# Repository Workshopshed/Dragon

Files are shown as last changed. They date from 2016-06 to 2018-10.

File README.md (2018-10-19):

# Dragon Detector
## Dragonboard 410c Project
This is the source code for the Dragon Detector project for more details of the electronics and build see https://www.element14.com/community/people/Workshopshed/blog and for the mechanical aspects see http://workshopshed.com/category/myprojects/dragon-detector/

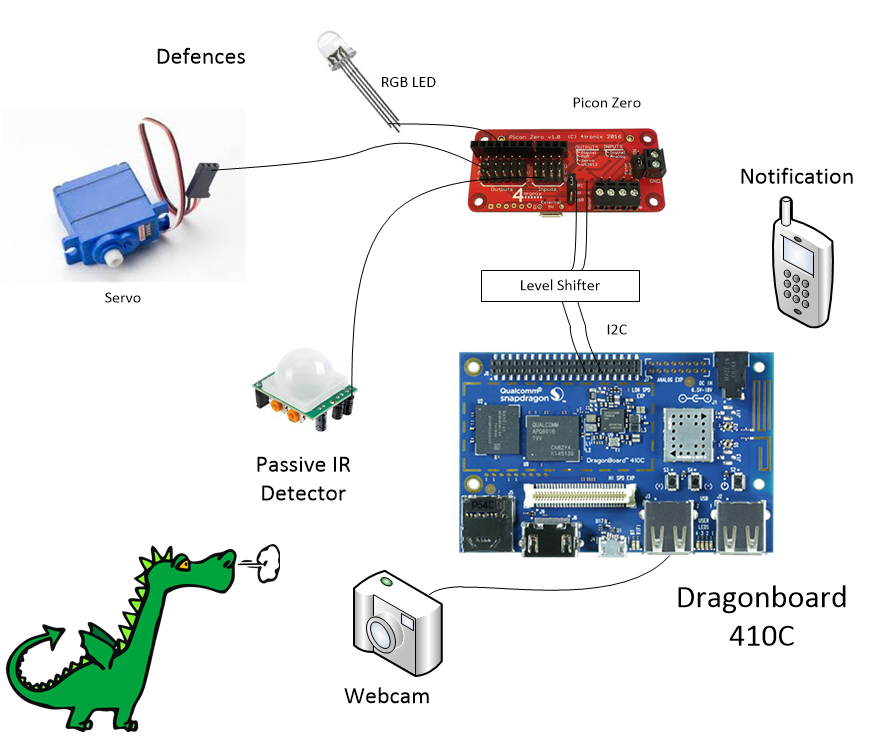
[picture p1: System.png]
System Diagram


Here it is in action, click image to see video

Demo Video (https://www.youtube.com/watch?v=9NGkGyWplvQ)

A short talk on the project https://skillsmatter.com/skillscasts/8225-linuxing-in-london

## Software Dependencies

Dropbox API - https://www.dropbox.com/developers/documentation/python#install

piconzero - http://4tronix.co.uk/blog/?p=1224

IFTTT Maker API - https://ifttt.com/maker

OpenCV - http://opencv.org/

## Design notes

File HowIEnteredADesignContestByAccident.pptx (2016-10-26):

## How I entered a $5000 design challenge by accident

By Andy Clark

## What is a design challenge?

- Free Stuff
- Company promotion
- Proposal
- Build
- Write up / Video
- Prizes

## 2015 Enchanted Objects Design Challenge

- Add enchantment to an every day object
- 16 weeks of soldering, 3D printing, coding and writing
- Won the grand prize Trip to New York Makers Faire

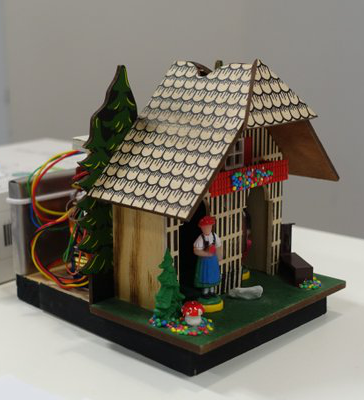
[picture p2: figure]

No More Design Challenges!

## March 2016

Tell us what you would make with a DragonBoard 410c for a chance to win your own

Qualcomm

I am entering this contest and wish your vote when polls open

Clem Martins

Some ideas are so far west they are another planet

Mark B

I'm really tempted to put in a completely ridiculous entry

Nico teWinkel

## My Entry

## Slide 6

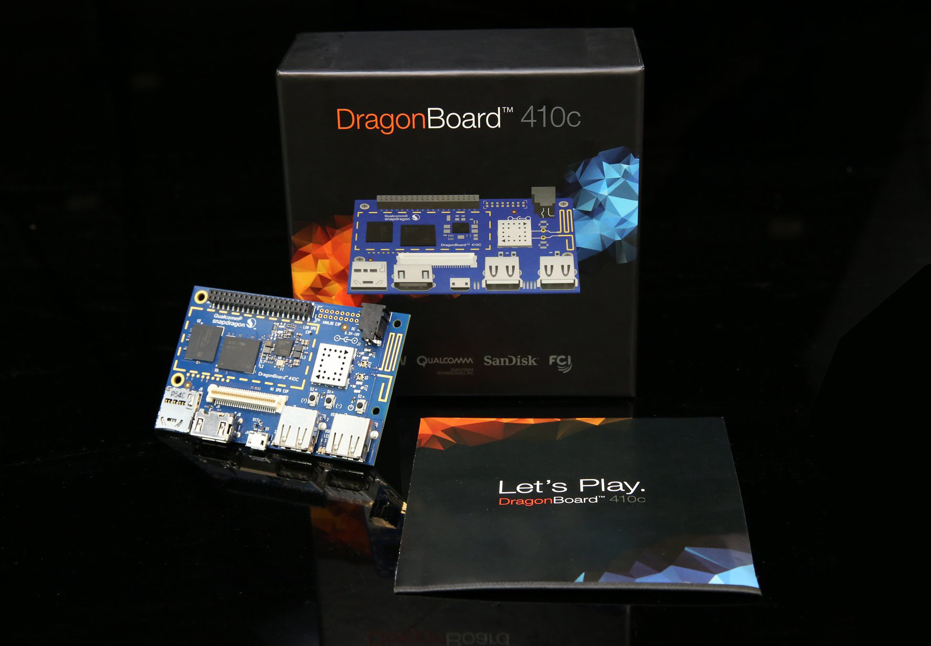
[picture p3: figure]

Photo thanks to Arrow.Com

## Setting up the DragonBoard

- Preinstalled Android image
- Community support at 96boards.org
- Reflashed with Debian image provided by Linaro

## OpenCV

“(Open Source Computer Vision) is a library of programming functions mainly aimed at real-time computer vision.”

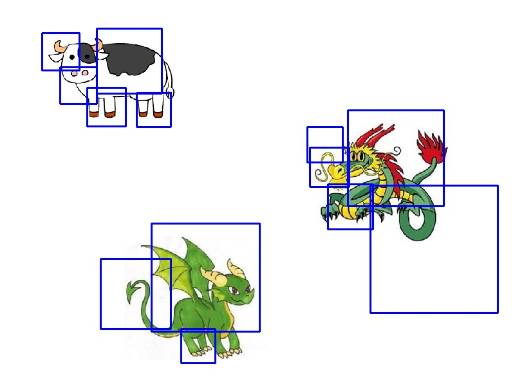
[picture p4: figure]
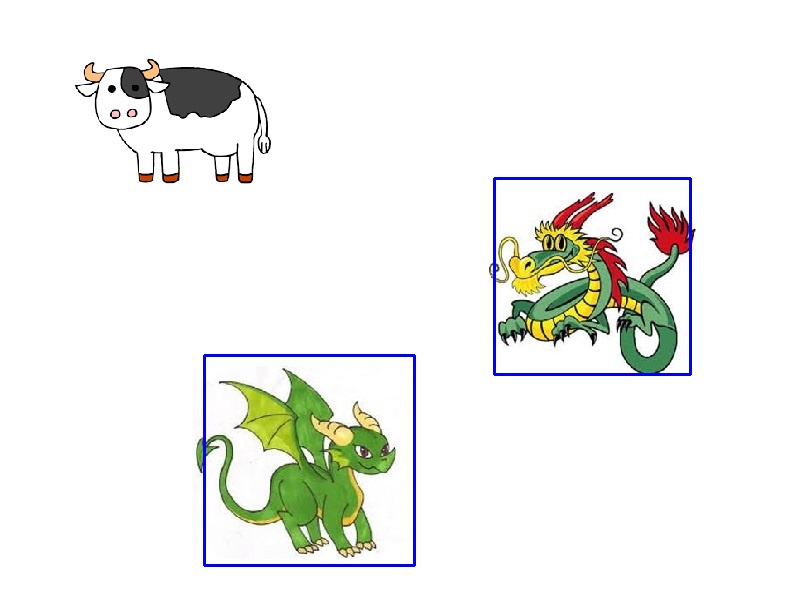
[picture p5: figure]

## GPIO General Purpose Input / Output

- Install drivers such as LibSoc
- No PWM
- 1.8v
- Ref: https://github.com/jackmitch/libsoc/blob/master/static-docs/docs/index.md

## Electronics

- Level Shifters
- Passive IR module
- USB Camera
- LEDs

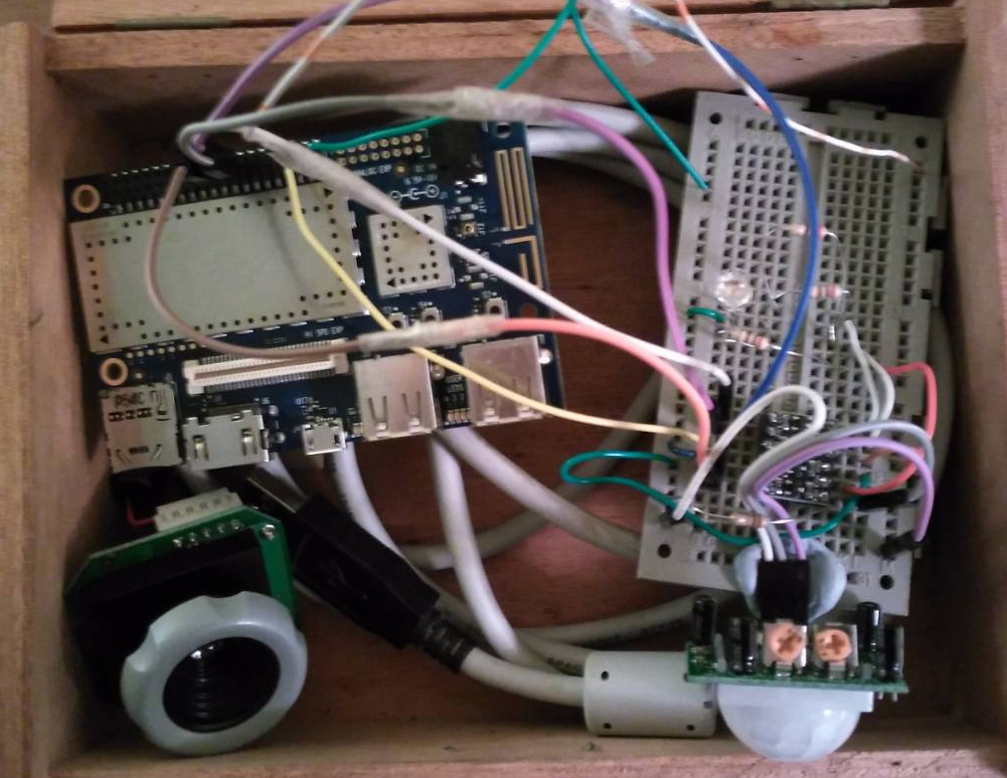
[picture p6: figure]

## So did I win $5000?

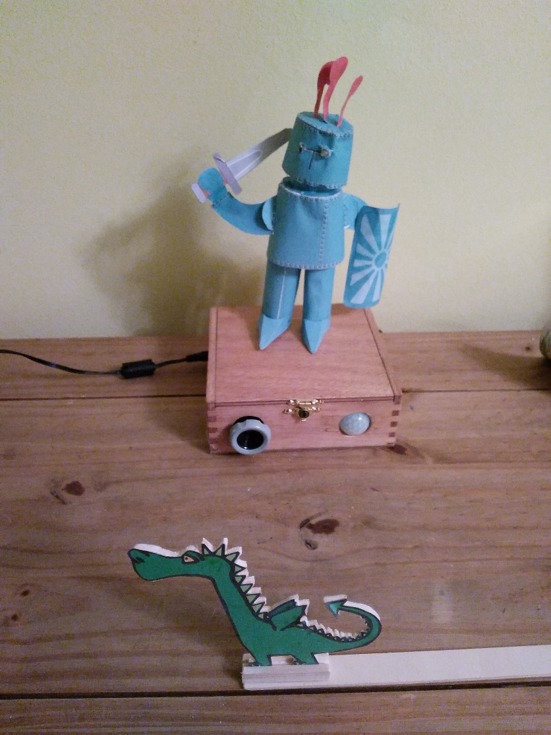
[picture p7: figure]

- Qualcomm Developer of the Month
- Arrow.com sponsoring

## Dragon Detector V2

- 3D Printed model
- PiConZero module for PWM
- Demo

## Questions?

https://wsshd.com/DragonDectector

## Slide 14

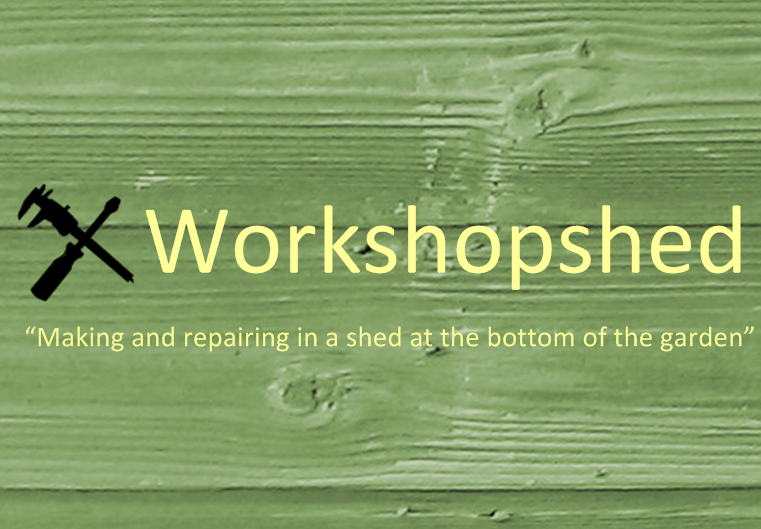
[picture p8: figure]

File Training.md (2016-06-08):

# Details of the training process for the Cascade Classifier in OpenCV

[Details of the OpenCV code development](https://www.element14.com/community/people/Workshopshed/blog/2016/05/20/dragonboard-410c-opencv)

The training application is very hungry for memory and used about 2.5GB on my system. It ran one of my CPUs at between 50% and 100%.

Conveniently the training application tells you how long it runs for, so on my first pass it tool 13 minutes for stage one and finished in about half an hour

Here's the output from the second run where I had a lot more images and set the false alarm rate much lower.

```
opencv_traincascade.exe -data Cascade -vec Dragons.vec -bg Negative.info -numPos 90 -numNeg 2078 -maxFalseAlarmRate 0.05 -numStages 5 -w 50 -h 50 -mode ALL
PARAMETERS:
cascadeDirName: Cascade
vecFileName: Dragons.vec
bgFileName: Negative.info
numPos: 90
numNeg: 2078
numStages: 5
precalcValBufSize[Mb] : 1024
precalcIdxBufSize[Mb] : 1024
acceptanceRatioBreakValue : -1
stageType: BOOST
featureType: HAAR
sampleWidth: 50
sampleHeight: 50
boostType: GAB
minHitRate: 0.995
maxFalseAlarmRate: 0.05
weightTrimRate: 0.95
maxDepth: 1
maxWeakCount: 100
mode: ALL

===== TRAINING 0-stage =====
<BEGIN
POS count : consumed   90 : 90
NEG count : acceptanceRatio    2078 : 1
Precalculation time: 11.939
+----+---------+---------+
|  N |    HR   |    FA   |
+----+---------+---------+
|   1|        1|        1|
+----+---------+---------+
|   2|        1|        1|
+----+---------+---------+
|   3|        1| 0.298845|
+----+---------+---------+
|   4|        1| 0.326275|
+----+---------+---------+
|   5|        1| 0.100096|
+----+---------+---------+
|   6|        1|0.0375361|
+----+---------+---------+
END>
Training until now has taken 0 days 1 hours 53 minutes 16 seconds.

===== TRAINING 1-stage =====
<BEGIN
POS count : consumed   90 : 90
NEG count : acceptanceRatio    2078 : 0.0275363
Precalculation time: 14.096
+----+---------+---------+
|  N |    HR   |    FA   |
+----+---------+---------+
|   1|        1|        1|
+----+---------+---------+
|   2|        1|        1|
+----+---------+---------+
|   3|        1| 0.679018|
+----+---------+---------+
|   4|        1| 0.416747|
+----+---------+---------+
|   5|        1| 0.227623|
+----+---------+---------+
|   6|        1| 0.102021|
+----+---------+---------+
|   7|        1| 0.159769|
+----+---------+---------+
|   8|        1|0.0866218|
+----+---------+---------+
|   9|        1| 0.045717|
+----+---------+---------+
END>
Training until now has taken 0 days 4 hours 26 minutes 52 seconds.

===== TRAINING 2-stage =====
<BEGIN
POS count : consumed   90 : 90
Premature end of JPEG file
NEG count : acceptanceRatio    2078 : 0.00243268
Precalculation time: 13.822
+----+---------+---------+
|  N |    HR   |    FA   |
+----+---------+---------+
|   1|        1|        1|
+----+---------+---------+
|   2|        1|        1|
+----+---------+---------+
|   3|        1|        1|
+----+---------+---------+
|   4|        1| 0.629451|
+----+---------+---------+
|   5|        1|  0.39846|
+----+---------+---------+
|   6|        1| 0.145332|
+----+---------+---------+
|   7|        1|0.0904716|
+----+---------+---------+
|   8|        1|0.0495669|
+----+---------+---------+
END>
Training until now has taken 0 days 6 hours 44 minutes 9 seconds.

===== TRAINING 3-stage =====
<BEGIN
POS count : consumed   90 : 90
Premature end of JPEG file
NEG count : acceptanceRatio    2078 : 0.000160029
Precalculation time: 12.939
+----+---------+---------+
|  N |    HR   |    FA   |
+----+---------+---------+
|   1|        1|        1|
+----+---------+---------+
|   2|        1|        1|
+----+---------+---------+
|   3|        1| 0.558229|
+----+---------+---------+
|   4|        1| 0.762271|
+----+---------+---------+
|   5|        1| 0.508181|
+----+---------+---------+
|   6|        1| 0.374398|
+----+---------+---------+
|   7|        1| 0.290664|
+----+---------+---------+
|   8|        1| 0.192974|
+----+---------+---------+
|   9|        1| 0.188643|
+----+---------+---------+
|  10|        1|  0.12897|
+----+---------+---------+
|  11|        1|0.0914341|
+----+---------+---------+
|  12|        1| 0.104909|
+----+---------+---------+
|  13|        1|0.0418672|
+----+---------+---------+
END>
Training until now has taken 0 days 10 hours 0 minutes 37 seconds.

===== TRAINING 4-stage =====
<BEGIN
POS count : consumed   90 : 90
Premature end of JPEG file
Premature end of JPEG file
Premature end of JPEG file
Premature end of JPEG file
Premature end of JPEG file
Premature end of JPEG file
Premature end of JPEG file
Premature end of JPEG file
Premature end of JPEG file
Premature end of JPEG file
Premature end of JPEG file
Premature end of JPEG file
Premature end of JPEG file
Premature end of JPEG file
Premature end of JPEG file
Premature end of JPEG file
Premature end of JPEG file
Premature end of JPEG file
Premature end of JPEG file
NEG count : acceptanceRatio    2078 : 9.49071e-06
Precalculation time: 12.259
+----+---------+---------+
|  N |    HR   |    FA   |
+----+---------+---------+
|   1|        1|        1|
+----+---------+---------+
|   2|        1|        1|
+----+---------+---------+
|   3|        1|        1|
+----+---------+---------+
|   4|        1| 0.770452|
+----+---------+---------+
|   5|        1| 0.591915|
+----+---------+---------+
|   6|        1| 0.421078|
+----+---------+---------+
|   7|        1| 0.381136|
+----+---------+---------+
|   8|        1| 0.275265|
+----+---------+---------+
|   9|        1|   0.1564|
+----+---------+---------+
|  10|        1| 0.128489|
+----+---------+---------+
|  11|        1| 0.149182|
+----+---------+---------+
|  12|        1| 0.114052|
+----+---------+---------+
|  13|        1|0.0524543|
+----+---------+---------+
|  14|        1|0.0822907|
+----+---------+---------+
|  15|        1|0.0548604|
+----+---------+---------+
|  16|        1|0.0202117|
+----+---------+---------+
END>
Training until now has taken 0 days 14 hours 45 minutes 51 seconds.
```

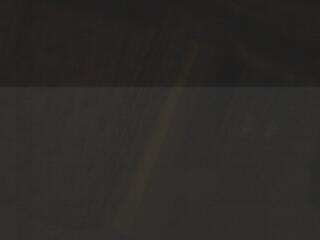
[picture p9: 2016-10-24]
outfile.jpeg

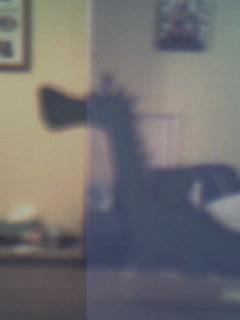
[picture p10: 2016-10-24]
CaptureInput2016-05-28T220832.969931.jpeg

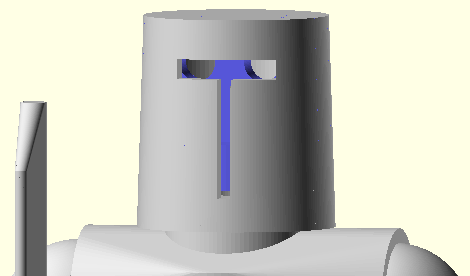
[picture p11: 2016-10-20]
3DModels/HeadWithCarrier.png

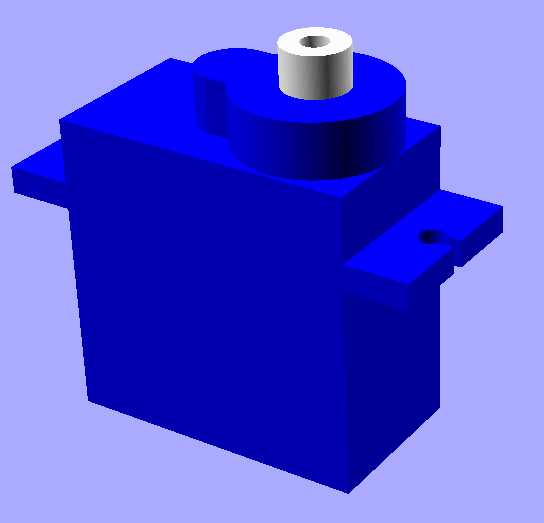
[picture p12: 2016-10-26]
3DModels/Servo.png

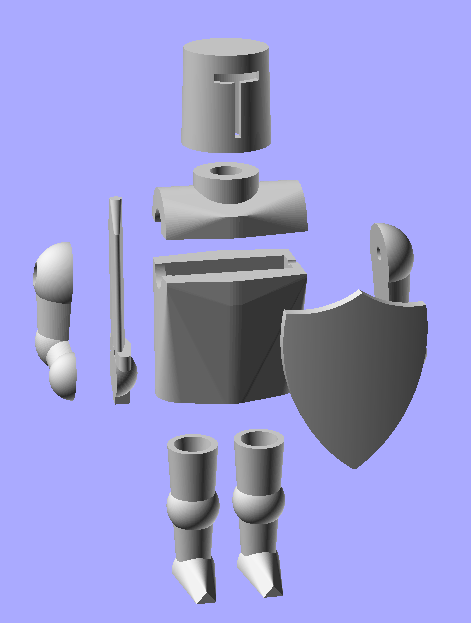
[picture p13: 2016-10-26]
3DModels/KnightExploded.png

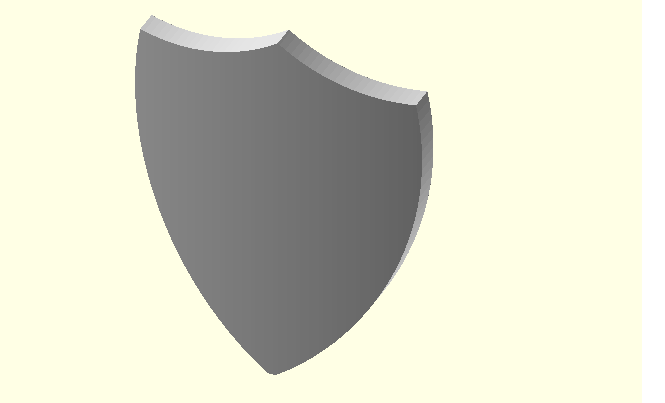
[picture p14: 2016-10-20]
3DModels/ShieldSimple.png

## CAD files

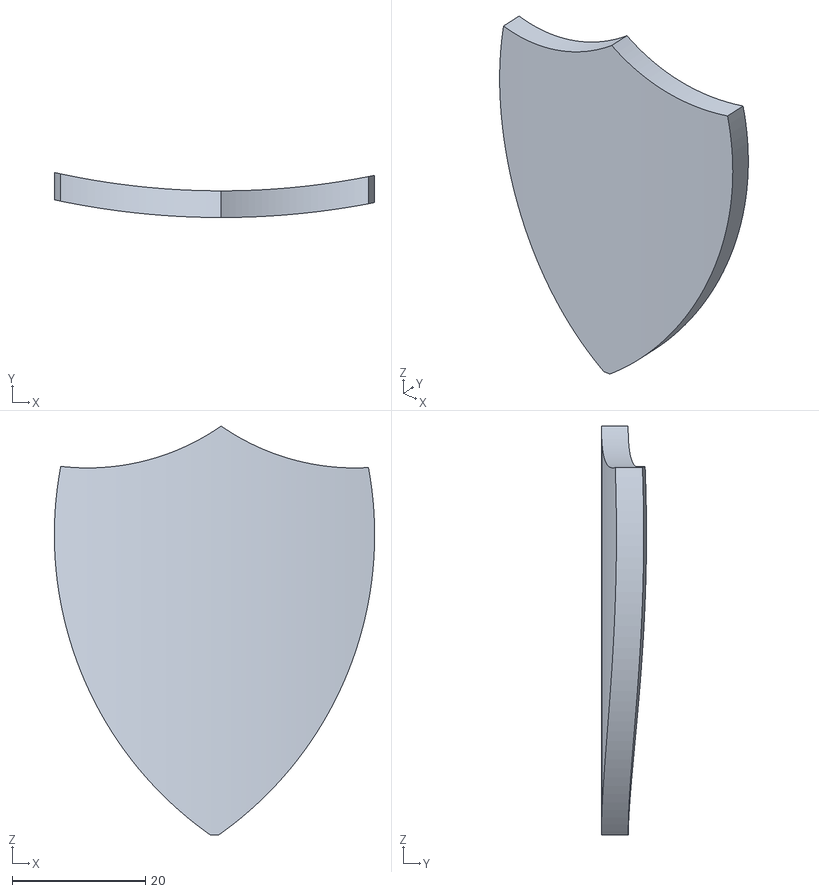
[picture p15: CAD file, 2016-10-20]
3DModels/ShieldSimple.stl
48.0 x 6.75 x 61.3

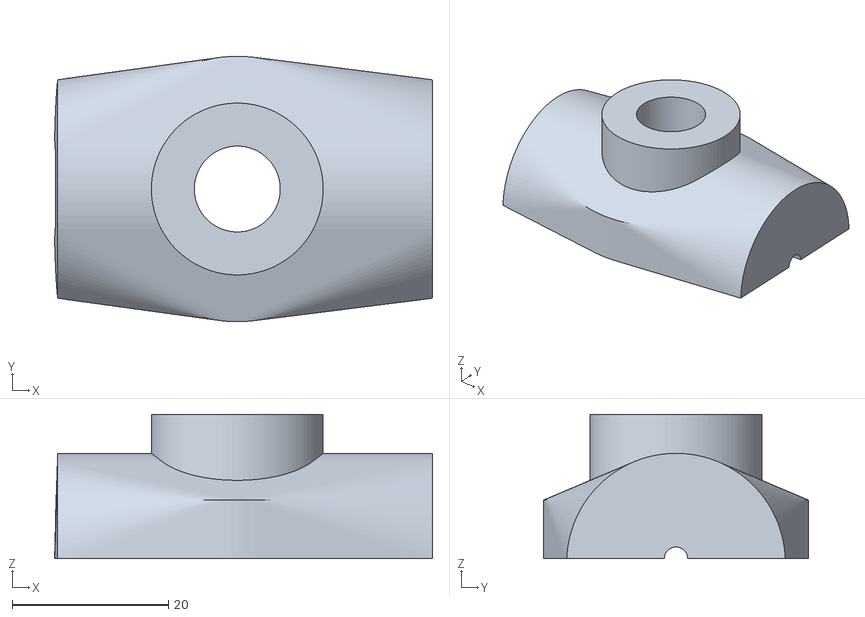
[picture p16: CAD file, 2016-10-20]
3DModels/BodyTop.stl
48.4 x 34.0 x 18.5

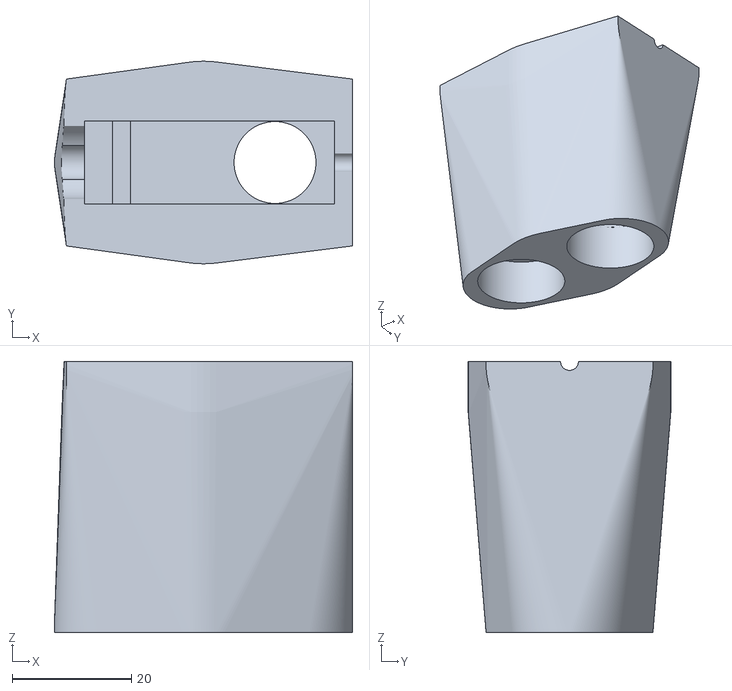
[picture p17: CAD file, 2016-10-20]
3DModels/Body.stl
50.0 x 34.0 x 45.5

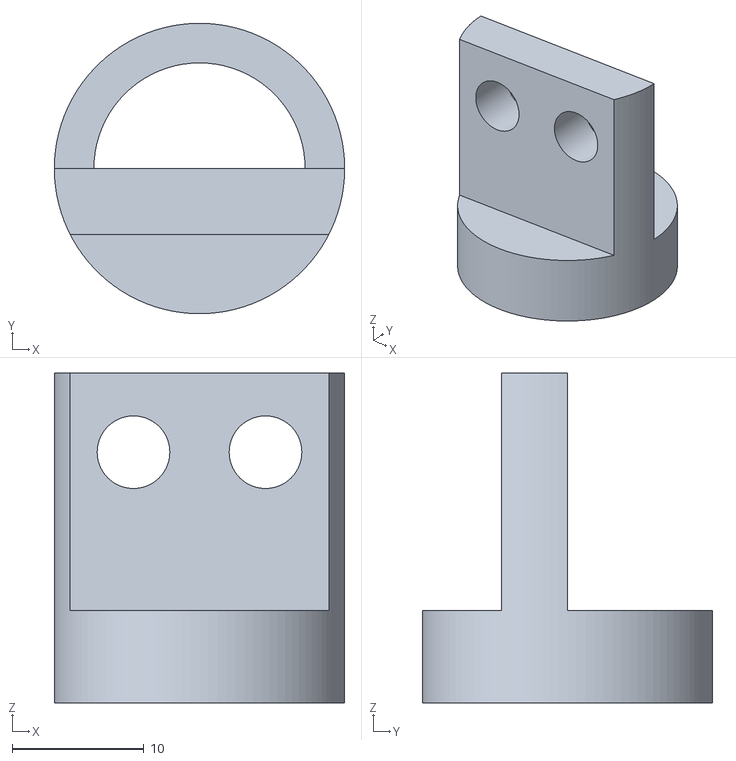
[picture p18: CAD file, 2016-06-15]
3DModels/LEDCarrier.stl
22.0 x 22.0 x 25.0

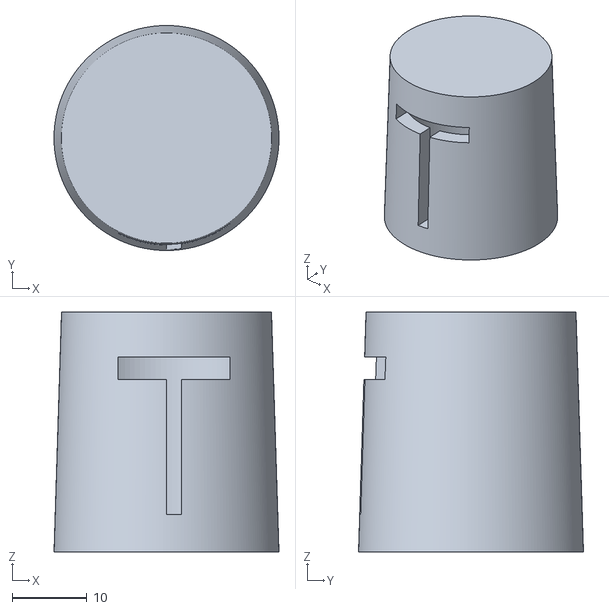
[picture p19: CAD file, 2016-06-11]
3DModels/Head.stl
30.0 x 30.0 x 32.0

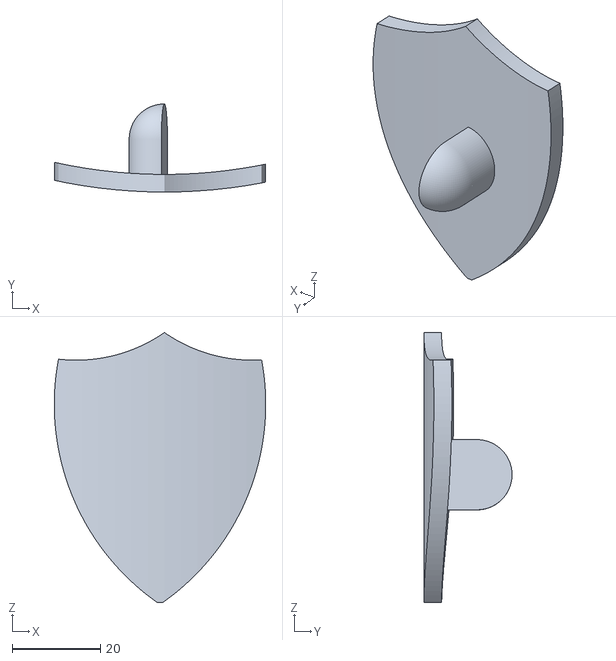
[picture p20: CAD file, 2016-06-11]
3DModels/Shield.stl
48.0 x 20.0 x 61.3

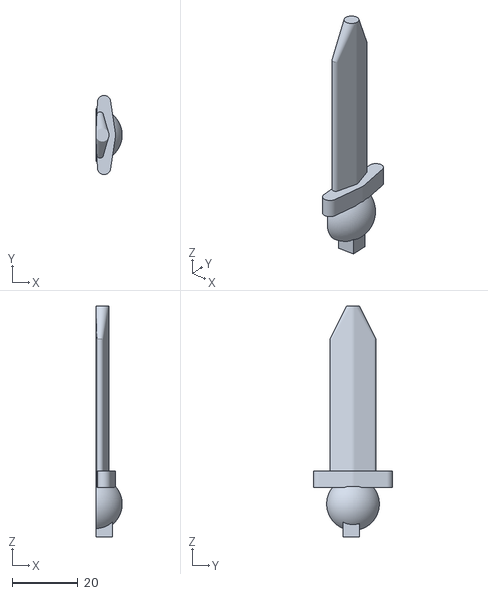
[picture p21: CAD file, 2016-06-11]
3DModels/Sword.stl
8.00 x 24.0 x 70.0

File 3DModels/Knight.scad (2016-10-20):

// Knight Model
use <SG90.scad>;

module shoe() {
    scale([1,1,1.2])
    difference(){
        rotate([0,45,0])
            hull() {
            cube([5,0.2,5], true);
            translate([0,25,0])
                rotate([0,90,90])
                    cylinder(0.2,r=8,true,$fn=200);
        }
        //Slice off bottom
        translate([0,15,-5])
            cube([20,35,10],true);
        //Tiedown
        translate([0,10,-1])
            cylinder(6,r=1,true,$fn=200);
        }
}

module leg() {
    difference(){
        union(){
        cylinder(42,r=6,r2=9,true,$fn=200);
        translate([0,0,42])
            cylinder(10,r=9,true,$fn=200);
        translate([0,0,26])     
        sphere(9.5,true,$fn=200);    
        translate([0,-25,0]) 
        shoe();
        }
        translate([0,0,-2]) 
            cylinder(60,r=4.5,r2=7,true,$fn=200);
    }
}

module base() {
    hull() {
    translate([-15,0,0]) 
    cylinder(2,r=10,true,$fn=200);
    cylinder(2,r=14,true,$fn=200);
    translate([15,0,0]) 
    cylinder(2,r=10,true,$fn=200);
    }
}

module shoulder() {
	size=14;
	width=23;
    hull() {
    translate([-width,0,0]) 
    rotate([0,90,0])
    cylinder(2,r=size,true,$fn=100);
    translate([0,0,-8]) 
    cylinder(16,r=size+3,true,$fn=100);
    translate([width,0,0]) 
    rotate([0,90,0])
    cylinder(2,r=size,true,$fn=100);
    }
}

module body() {
	difference() {
		hull() {
			translate([0,0,45])
				shoulder();
			base();
		}
		translate([-27,-20,45.5])
			cube([55,42,22]);
		translate([-15.25,-7,23])
			cube([3,14,34]);
		translate([-20,-7,28])
			cube([42,14,24]);
		translate([-30,0,45.5])
			rotate([0,90,0])
				cylinder(30,d=12.2,true,$fn=100);
        hull(){
       	translate([-30,0,39])
			rotate([0,90,0])
				cylinder(30,d=5.75,true,$fn=100);
        translate([-30,0,44])
			rotate([0,90,0])
				cylinder(30,d=5.75,true,$fn=100);
        }
		translate([-12,0,-40])
			cylinder(50,r=9.25,true,$fn=200);
		translate([20,0,45.5])
			rotate([0,90,0])
				cylinder(10,d=3,true,$fn=100);
		translate([12,0,-40])
			cylinder(50,r=9.25,true,$fn=200);
		translate([12,0,9.8])
			cylinder(21,r=9.25,r2=6.5,true,$fn=200);

	}
}

module body_top() {
	
	difference() {
		union() {
			hull() {
				translate([0,0,45])
					shoulder();
				base();
			}
			translate([0,0,50])
			cylinder(14,d=22,true,$fn=100);
		}	
		translate([-27,-20,-3.5])
			cube([55,42,49]);
		translate([-15.25,-7,23])
			cube([3,14,34]);
		translate([-20,-7,28])
			cube([42,14,24]);
		translate([-30,0,45.5])
			rotate([0,90,0])
				cylinder(30,d=12.2,true,$fn=100);
		translate([20,0,45.5])
			rotate([0,90,0])
				cylinder(10,d=3,true,$fn=100);
		translate([0,0,45.5])
			cylinder(30,d=11,true,$fn=100);
		translate([15,0,45])
			rotate([0,-55,0])
				cylinder(18,d=11,true,$fn=100);		
	}
}

module head() {
    difference() {
    cylinder(32,r=15,r2=14,true,$fn=200);
    //Eye slot
    translate([0,-20,5])
        cube([2,10,20]);
    translate([-6.5,-15,23])
        cube([15,10,3]);
	//Neck
	translate([0,0,-5])
		cylinder(35,d=23,true,$fn=100);
    }
}

module LEDCarrier() {
difference() {
		cylinder(25,d=22,true,$fn=100);
		translate([-15,0,7])
			cube([30,15,20]);
		translate([-15,-15,7])
			cube([30,10,20]);
		translate([5,2,19])
			rotate([90,90,0])
				cylinder(10,d=5.5,true,$fn=80);
		translate([-5,2,19])
			rotate([90,90,0])
				cylinder(10,d=5.5,true,$fn=80);
		translate([0,0,-1])
			rotate([0,0,180])
				halfcylinder(15,8);
	}
}
module halfcylinder(height,radius) {
	difference() {
	cylinder(height,r=radius,true,$fn=80);
	translate([-radius-1,0,-1])
		cube([(radius*2)+2,radius+2,height+2]);
	}
}


module arm() {
    difference() {
        translate([0,0,45]) {
            sphere(12,true,$fn=200);
            translate([0,0,-23]) {
                cylinder(23,r=9,r2=11,true,$fn=100);
                sphere(10,true,$fn=100);
                translate([0,0,-3]) {
                rotate([90,0,00])
                cylinder(30,r=7,r2=6,true,$fn=100);
                translate([0,-25,0])
                sphere(8,true,$fn=200);
                }
            }
        }
        translate([0,-40,0])
            cube([20,100,100]);
		translate([-15,0,45.25])
			rotate([0,85,0])
				cylinder(20,d=5,true,$fn=100);
		translate([-20,0,45.25])
			rotate([0,85,0])
				cylinder(10,d=8,true,$fn=100);

    }
}
module sword() {
     union() {
        hull() {
            translate([2.5,0,0]) 
            cylinder(5,r=2,true,$fn=200);
            translate([3,10,0]) 
            cylinder(5,r=3,true,$fn=200);
            translate([2.5,20,0]) 
            cylinder(5,r=2,true,$fn=200);
        }
        hull() {
            translate([1.3,4,5]) 
            cylinder(40,r=1,true,$fn=200);
            translate([2,10,5]) 
            cylinder(50,r=2,true,$fn=200);
            translate([1.3,16,5]) 
            cylinder(40,r=1,true,$fn=200);
        }
        translate([0,7,-15])
        cube([5,5,20]);
        translate([0,10,-5])
            difference() {
                sphere(8,true,$fn=100);
                translate([-10,-10,-10])
                    cube([10,20,20]);
            }
	}
    
}

module shield() {
	translate([30,15,29])
	   rotate([0,-5,0])
	   //Hand + handle
       difference() {
		   union() {
			   sphere(8,true,$fn=200);
			   rotate([90,0,0])
				  cylinder(8,r=8,$fn=200);
		   }	   
           translate([0,-10,-10])
                    cube([10,20,20]);
	   }
	intersection() {
	difference() {
	cube([60,10,70]);
	translate([10,15,90])
		rotate([90,0,0])
			cylinder(20,r=35,true,$fn=500);
	translate([50,15,90])
		rotate([90,0,0])
			cylinder(20,r=35,true,$fn=500);		
	}
	translate([60,15,45])
		rotate([90,0,0])
			cylinder(20,r=55,true,$fn=400);
	translate([-2,15,45])
		rotate([90,0,0])
			cylinder(20,r=55,true,$fn=400);
	translate([30,122,0])
		doughnut();
	}
}
module doughnut() {
	difference() {
		cylinder(70,r=119,true,$fn=1000);
		translate([0,0,-5])
		cylinder(80,r=115,true,$fn=1000);
		
	}
}

module knight() {
	explode=0; //20*$t;
	armpos=28.1;
	translate([-armpos-explode,0,0])
		rotate([0,5,0])
			color([0.8,0.8,0.8]) arm();
	translate([-armpos-(explode/2),-35,24])
		color([0.8,0.8,0.8]) sword();
	translate([armpos+explode,0,0])
		mirror([1,0,0]) 
			rotate([0,5,0])
				color([0.8,0.8,0.8]) arm();
	translate([0,0,59+explode])
		color([0.8,0.8,0.8]) head();
    color([0.8,0.8,0.8]) body();
	translate([0,0,explode/2])
	color([0.8,0.8,0.8]) body_top();
    translate([-12,0,-40-explode])
        color([0.8,0.8,0.8]) leg();
    translate([12,0,-40-explode])
        color([0.8,0.8,0.8]) leg();
	translate([-4+(explode/4),-41-(explode/2),-10])
		color([0.8,0.8,0.8]) shield();
	translate([0,0,65+explode])	
		color([0.4,0.4,1]) LEDCarrier();	
}

knight();

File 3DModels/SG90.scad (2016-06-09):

// By Mikael Lövqvist on 2016-04-27
// https://github.com/ledalert/cadmodel-sg90
// http://www.ledalert.org/approximate-model-of-sg90-servo/

module sg90() {
	$fn = 100;
	color("blue") difference() {
		union() {
			translate([0,0,22.5/2]) cube([22.5,12.2,22.5], center=true);
			translate([0,0,16.75]) cube([32.2,12.2,2], center=true);

			translate([0,0,22.5-1]) {
				hull() {
					translate([-1,0,0]) cylinder(d=5.5, h=4+1);
					translate([1,0,0]) cylinder(d=5.5, h=4+1);
				}

				translate([5.5,0,0]) cylinder(d=11.6, h=4+1);
			}

		}	

		translate([-32.5/2+2,0,16.75-2]) {
			cylinder(d=2, h=2+2);
			translate([-2,0,2]) cube([4,1,2+2], center=true);
		}
		translate([32.5/2-2,0,16.75-2]) {
			cylinder(d=2, h=2+2);
			translate([2,0,2]) cube([4,1,2+2], center=true);
		}
	}
	color("white") translate([5.5,0,22.5-1+4]) {
		difference() {
			cylinder(d=4.8, h=3+1);
			translate([0,0,1]) cylinder(d=2, h=4);
		}
	}
}

sg90();

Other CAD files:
3DModels/ShieldSimple.scad

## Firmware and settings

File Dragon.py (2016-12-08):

#!/usr/bin/env python

from StringIO import StringIO
import pycurl
import signal, sys
import cv2
from subprocess import call
import piconzero as pz
from Queue import Queue
from threading import Thread
import datetime,time
import dropbox, os


# Ref https://www.troyfawkes.com/learn-python-multithreading-queues-basics/
#     https://docs.python.org/2/library/queue.html

class ServoTask:
    def __init__(self, angle, delay):
        self.angle = angle
        self.delay = delay

    def run(self):
        # print self.angle
        pz.setOutput(0, self.angle)
        time.sleep(self.delay)


class LEDTask:
    def __init__(self, rgb, delay):
        self.rgb = rgb
        self.delay = delay

    def run(self):
        # print self.rgb.red, self.rgb.green, self.rgb.blue
        pz.setOutput(1, self.rgb.red)
        pz.setOutput(2, self.rgb.green)
        pz.setOutput(3, self.rgb.blue)
        time.sleep(self.delay)


class RGB:
    def __init__(self, red, green, blue):
        self.red = red
        self.green = green
        self.blue = blue


def processq(q):
    while True:
        task = q.get()
        task.run()
        q.task_done()


def call_api(url):
    r = StringIO()
    c = pycurl.Curl()
    c.setopt(c.URL, url)
    c.setopt(c.CONNECTTIMEOUT, 10)
    c.setopt(c.TIMEOUT, 60)
    c.setopt(c.WRITEFUNCTION, r.write)
    c.perform()
    c.close()
    return r.getvalue()


def get_IFTTTkey():
    with open('IFTTTKey.conf', 'r') as f:
        key = f.readline()
    f.close()
    return key


# Have created a Dropbox App folder with the DropBox Developer console
# https://www.dropbox.com/developers/apps
# Get the access token from a file, as created by above console
def get_dropboxkey():
    with open('DropBoxKey.conf', 'r') as f:
        key = f.readline()
    f.close()
    return key


def notify(numDragons, key):
    url = "https://maker.ifttt.com/trigger/DragonDetected/with/key/" + key + "?value1=" + str(numDragons)
    r = call_api(url)
    print r


# Simplified upload from the updown.py example
# https://github.com/dropbox/dropbox-sdk-python/blob/master/example/updown.py
def upload(sourcefile, destfile, overwrite=False):
    """Upload a file.

    Return the request response, or None in case of error.
    """
    mode = (dropbox.files.WriteMode.overwrite
            if overwrite
            else dropbox.files.WriteMode.add)
    mtime = os.path.getmtime(sourcefile)
    with open(sourcefile, 'rb') as f:
        data = f.read()
    try:
        res = dbx.files_upload(
            data, destfile, mode,
            client_modified=datetime.datetime(*time.gmtime(mtime)[:6]),
            mute=True)
    except dropbox.exceptions.ApiError as err:
        print('*** API error', err)
        return None
    print 'Uploaded', res.name.encode('utf8')
    return res


def purge_old_files(daystokeep):
    files = 0
    print 'Deleting dropbox files older than {} days'.format(daystokeep)
    now = datetime.datetime.now()
    for entry in dbx.files_list_folder('').entries:
        delta = now - entry.server_modified
        if delta.days > daystokeep:
            files += 1
            print 'Deleting {} from {}'.format(entry.name, entry.server_modified)
            try:
                dbx.files_delete('/' + entry.name)
            except dropbox.exceptions.ApiError as err:
                print('*** API error', err)
                return None
    if files > 0:
        print 'Deleted {} files'.format(files)


def capture():
    filename = "CaptureInput" + datetime.datetime.now().isoformat().replace(":", "") + ".jpeg"
    cmdline = "streamer -c /dev/video0 -b 32 -f jpeg -o " + filename
    call(cmdline, shell=True)
    return cv2.imread(filename)


def detect(img):
    dclassifier = cv2.CascadeClassifier('DragonClassifier50x50-5v2.xml')

    detected = 0

    dragons = dclassifier.detectMultiScale(img)
    for (x, y, w, h) in dragons:
        cv2.rectangle(img, (x, y), (x + w, y + h), (255, 0, 0), 2)
        detected += 1

    newfilename = ""
    if detected > 0:
        newfilename = "Detected" + datetime.datetime.now().isoformat().replace(":", "") + ".jpg"
        cv2.imwrite(newfilename, img)

    print(str(detected) + " dragons")
    print ""
    return detected, newfilename


def sensor_activated():
    return pz.readInput(0)


def waitforaction():
    # Wait till both queues are empty
    qLED.join()
    qServo.join()


def deactivate_defences():
    print "Looking for Dragons"
    qLED.put(LEDTask(RGB(0, 50, 0), 0.5))
    waitforaction()


def activated():
    # Flash blue
    print "Motion detected"
    qServo.put(ServoTask(120, 0.2))
    qLED.put(LEDTask(RGB(0, 0, 50), 0.5))
    qLED.put(LEDTask(RGB(0, 0, 0), 0.5))
    qLED.put(LEDTask(RGB(0, 0, 50), 0.5))
    qLED.put(LEDTask(RGB(0, 0, 0), 0.5))
    qLED.put(LEDTask(RGB(0, 0, 50), 0.5))
    waitforaction()


def activate_defences():
    print "Dragon detected"
    # Three sword blows
    for f in range(1, 4, 1):
        qServo.put(ServoTask(30, 0.5))
        for i in range(30, 120, 2):
            qServo.put(ServoTask(i, 0.01))

    greenlim = 30
    for f in range(1, 8, 1):
        qLED.put(LEDTask(RGB(80, greenlim, 0), 0.5))
        for i in range(greenlim, 0, -1):
            qLED.put(LEDTask(RGB(80, i, 0), 0.01))
        for i in range(0, greenlim, 1):
            qLED.put(LEDTask(RGB(80, i, 0), 0.01))
    # And back to red
    for i in range(greenlim, 0, -1):
        qLED.put(LEDTask(RGB(80, i, 0), 0.01))

    waitforaction()


# Handle exit and kill from OS
def set_exit_handler(func):
    signal.signal(signal.SIGTERM, func)


def on_exit(sig, func=None):
    print "Exiting DragonDetector"
    pz.cleanup()
    sys.exit(1)


def initialise():
    # Setup
    pz.init()
    pz.setOutputConfig(0, 2)  # set output 0 to Servo
    pz.setOutputConfig(1, 1)  # set output 1 to PWM
    pz.setOutputConfig(2, 1)  # set output 2 to PWM
    pz.setOutputConfig(3, 1)  # set output 3 to PWM
    pz.setInputConfig(0, 0)  # set input 1 to digital

    # Setup Action queues
    global qLED
    qLED = Queue(maxsize=0)
    global qServo
    qServo = Queue(maxsize=0)

    workerLED = Thread(target=processq, args=(qLED,))
    workerLED.setDaemon(True)
    workerLED.start()

    workerServo = Thread(target=processq, args=(qServo,))
    workerServo.setDaemon(True)
    workerServo.start()

    # Initialise dropbox
    global dbx
    dbx = dropbox.Dropbox(get_dropboxkey())


def main():
    try:
        initialise()
        while True:
            deactivate_defences()
            time.sleep(10)  # Avoid rapid retriggering
            while not sensor_activated():
                time.sleep(0.2)
            activated()
            image = capture()
            dragons, outfile = detect(image)
            if dragons > 0:
                notify(dragons, get_IFTTTkey())
                upload(outfile, '/' + outfile, True)
                activate_defences()
                purge_old_files(30)  # Keep 30 days of history
    except KeyboardInterrupt:
        print 'Stopping...'
        on_exit(None)


# Run program
if __name__ == '__main__':
    set_exit_handler(on_exit)
    sys.exit(main())

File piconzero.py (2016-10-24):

# Python library for 4tronix Picon Zero
# Note that all I2C accesses are wrapped in try clauses with repeats

import smbus, time
 
bus = smbus.SMBus(1) # For revision 1 Raspberry Pi, change to bus = smbus.SMBus(0)

pzaddr = 0x22 # I2C address of Picon Zero

#---------------------------------------------
# Definitions of Commands to Picon Zero
MOTORA = 0
OUTCFG0 = 2
OUTPUT0 = 8
INCFG0 = 14
SETBRIGHT = 18
UPDATENOW = 19
RESET = 20
#---------------------------------------------

#---------------------------------------------
# General variables
DEBUG = False
RETRIES = 10   # max number of retries for I2C calls
#---------------------------------------------

#---------------------------------------------
# Get Version and Revision info
def getRevision():
    for i in range(RETRIES):
        try:
            rval = bus.read_word_data (pzaddr, 0)
            return [rval/256, rval%256]
        except:
            if (DEBUG):
                print "Error in getRevision(), retrying"
#---------------------------------------------


#---------------------------------------------
# motor must be in range 0..1
# value must be in range -128 - +127
# values of -127, -128, +127 are treated as always ON,, no PWM
def setMotor (motor, value):
    if (motor>=0 and motor<=1 and value>=-128 and value<128):
        for i in range(RETRIES):
            try:
                bus.write_byte_data (pzaddr, motor, value)
                break
            except:
                if (DEBUG):
                    print "Error in setMotor(), retrying"

def forward (speed):
    setMotor (0, speed)
    setMotor (1, speed)

def reverse (speed):
    setMotor (0, -speed)
    setMotor (1, -speed)

def spinLeft (speed):
    setMotor (0, -speed)
    setMotor (1, speed)

def spinRight (speed):
    setMotor (0, speed)
    setMotor (1, -speed)

def stop():
    setMotor (0, 0)
    setMotor (1, 0)

#---------------------------------------------

#---------------------------------------------
# Read data for selected input channel (analog or digital)
# Channel is in range 0 to 3
def readInput (channel):
    if (channel>=0 and channel <=3):
        for i in range(RETRIES):
            try:
                return bus.read_word_data (pzaddr, channel + 1)
            except:
                if (DEBUG):
                    print "Error in readChannel(), retrying"
                
#---------------------------------------------
    
#---------------------------------------------
# Set configuration of selected output
# 0: On/Off, 1: PWM, 2: Servo, 3: WS2812B
def setOutputConfig (output, value):
    if (output>=0 and output<=5 and value>=0 and value<=3):
        for i in range(RETRIES):
            try:
                bus.write_byte_data (pzaddr, OUTCFG0 + output, value)
                break
            except:
                if (DEBUG):
                    print "Error in setOutputConfig(), retrying"
#---------------------------------------------

#---------------------------------------------
# Set configuration of selected input channel
# 0: Digital, 1: Analog
def setInputConfig (channel, value, pullup = False):
    # type: (object, object, object) -> object
    if (channel>=0 and channel <=3 and value>=0 and value<=3):
        if (value==0 and pullup==True):
            value = 128
        for i in range(RETRIES):
            try:
                bus.write_byte_data (pzaddr, INCFG0 + channel, value)
                break
            except:
                if (DEBUG):
                    print "Error in setInputConfig(), retrying"
#---------------------------------------------

#---------------------------------------------
# Set output data for selected output channel
# Mode  Name    Type    Values
# 0     On/Off  Byte    0 is OFF, 1 is ON
# 1     PWM     Byte    0 to 100 percentage of ON time
# 2     Servo   Byte    -100 to + 100 Position in degrees
# 3     WS2812B 4 Bytes 0:Pixel ID, 1:Red, 2:Green, 3:Blue
def setOutput (channel, value):
    if (channel>=0 and channel<=5):
        for i in range(RETRIES):
            try:
                bus.write_byte_data (pzaddr, OUTPUT0 + channel, value)
                break
            except:
                if (DEBUG):
                    print "Error in setOutput(), retrying"
#---------------------------------------------

#---------------------------------------------
# Set the colour of an individual pixel (always output 5)
def setPixel (Pixel, Red, Green, Blue, Update=True):
    pixelData = [Pixel, Red, Green, Blue]
    for i in range(RETRIES):
        try:
            bus.write_i2c_block_data (pzaddr, Update, pixelData)
            break
        except:
            if (DEBUG):
                print "Error in setPixel(), retrying"

def setAllPixels (Red, Green, Blue, Update=True):
    pixelData = [100, Red, Green, Blue]
    for i in range(RETRIES):
        try:
            bus.write_i2c_block_data (pzaddr, Update, pixelData)
            break
        except:
            if (DEBUG):
                print "Error in setAllPixels(), retrying"

def updatePixels ():
    for i in range(RETRIES):
        try:
            bus.write_byte_data (pzaddr, UPDATENOW, 0)
            break
        except:
            if (DEBUG):
                print "Error in updatePixels(), retrying"
                        
#---------------------------------------------

#---------------------------------------------
# Set the overall brightness of pixel array
def setBrightness (brightness):
    for i in range(RETRIES):
        try:
            bus.write_byte_data (pzaddr, SETBRIGHT, brightness)
            break
        except:
            if (DEBUG):
                print "Error in setBrightness(), retrying"
#---------------------------------------------

#---------------------------------------------
# Initialise the Board (same as cleanup)
def init (debug=False):
    DEBUG = debug
    for i in range(RETRIES):
        try:
            bus.write_byte_data (pzaddr, RESET, 0)
            break
        except:
            if (DEBUG):
                print "Error in init(), retrying"
    time.sleep(0.01)  #1ms delay to allow time to complete
    if (DEBUG):
        print "Debug is", DEBUG
#---------------------------------------------

#---------------------------------------------
# Cleanup the Board (same as init)
def cleanup ():
    for i in range(RETRIES):
        try:
            bus.write_byte_data (pzaddr, RESET, 0)
            break
        except:
            if (DEBUG):
                print "Error in cleanup(), retrying"
    time.sleep(0.001)   # 1ms delay to allow time to complete
#---------------------------------------------

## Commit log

2016-05-17 OpenCV Tests
    Some simple tests for OpenCV in python
    Issues with the paths for the classifiers for some reason so copied
    locally
    [TestOpenCVClassifier.py]
2016-05-28 Bug fixing and timing adjustment
    [Dragon.py]
2016-06-08 3D Models
    [Knight.scad]
2016-06-09 Updated Knight
    [Knight.scad, SG90.scad]
2016-06-09 Knight
    Exploded shield
    [Knight.scad]
2016-06-11 Knight
    Updated Knight plus model parts
    [Body.stl, BodyTop.stl, Head.stl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]
2016-06-11 Knight
    Made neck opening larger so will slide onto body
    [Head.stl, Knight.scad]
2016-06-11 Knight
    Added hole to body for screw
    [Body.stl, Knight.scad]
2016-06-15 Knight
    LED Carrier
    [Knight.scad, LEDCarrier.stl]
2016-06-16 Knight
    Change to the body so that the hole for the wires is circular
    [Body.stl, Knight.scad]
2016-06-17 Knight
    Added extra slot for the servo plus shrank arm hole
    [Body.stl, BodyTop.stl, Knight.scad]
2016-06-18 Knight
    Changed the leg so the hole in the bottom was larger to get a servo
    connector through, changed the top so that it was parallel and hence
    fixed into body better
    [Knight.scad]
2016-10-20 Simple shield
    Model of a simplified shield with no handle
    [ShieldSimple.scad, ShieldSimple.stl]
2016-10-20 Revert "Simple shield"
    This reverts commit dffc9fa459ae2383ab8d1be00c95630e3726b250.
    [ShieldSimple.scad, ShieldSimple.stl]
2016-10-20 Revert "Revert "Simple shield""
    This reverts commit b17dcfde8a042f26dd98184f8fa68841f4b8c744.
    [ShieldSimple.scad, ShieldSimple.stl]
2016-10-24 Test Code
    Sensor test using the Picon Zero board
2016-11-12 DragonDetector
    Fixed issue with sleep
    Added #! line to show shell how to run it
    [Dragon.py]
2016-12-08 Dragon code
    Fix extra ;
    [Dragon.py]
